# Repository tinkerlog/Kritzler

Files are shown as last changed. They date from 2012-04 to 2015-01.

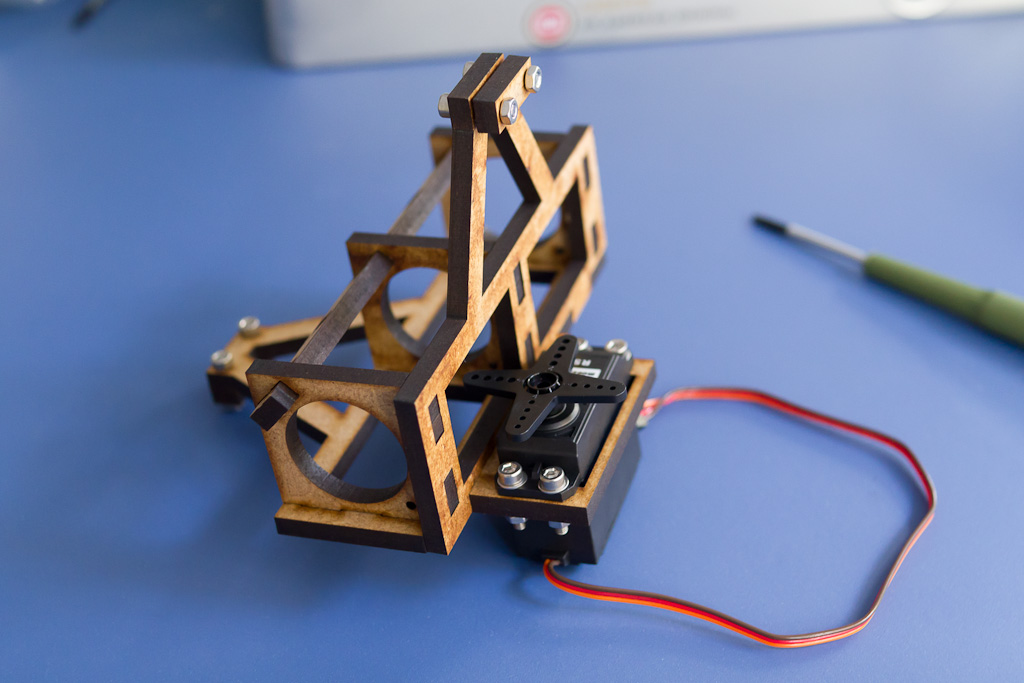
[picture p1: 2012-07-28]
doc/img/m_img-3472.jpg

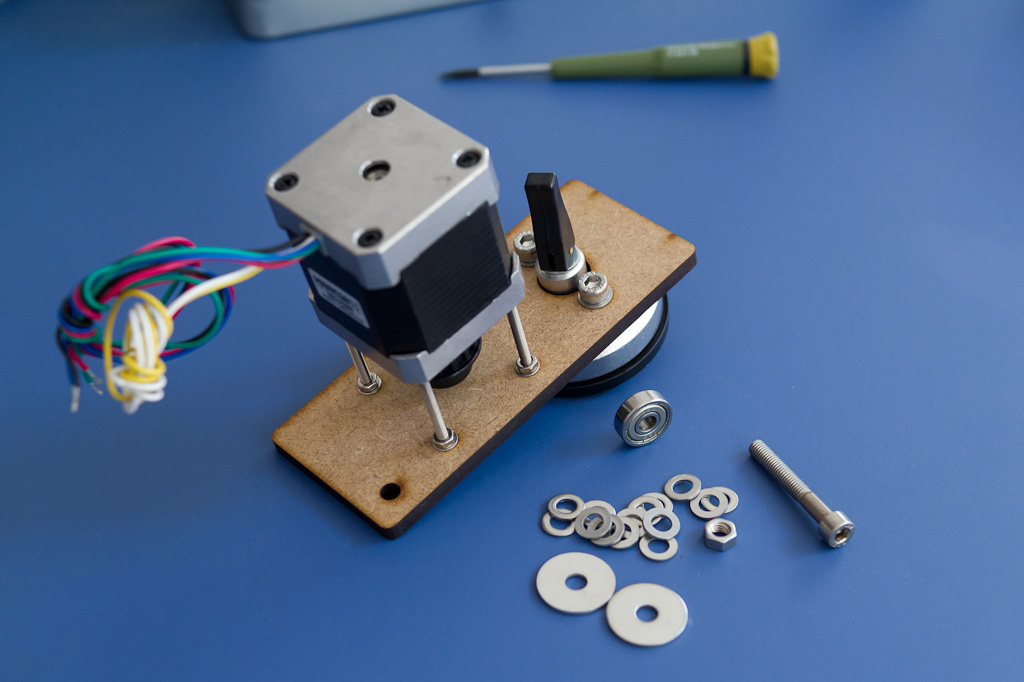
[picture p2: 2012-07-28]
doc/img/m_img-3442.jpg

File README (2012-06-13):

==============
 Der Kritzler
==============

 Der Kritzler is a software and hardware platform for developing wall plotters. 
 It consists of a set of Processing sketches (see src/ folder), Arduino firmware 
 (firmware/ folder) and some electronics (some files in the design/ folder). 

 More can be found here:
 http://tinkerlog.com/2011/09/02/der-kritzler/
 
 If you want me to pull your changes, please consider:
 * Use spaces, no tabs.
 * Indention: 2 spaces.

 src/ 
      Contains Processing/Java sources, ready to use in Eclipse.
      Take a look at http://processing.org/learning/eclipse/
      to see how to set things up.
      
 firmware/
      Contains Arduino firmware for the Kritzler.

 jpg_to_svg_bw.sh
      Script to convert a bitmap into an SVG.
      Needs imagemagick and potrace.
    
 jpg_to_svg.sh
      Starts the processing sketch to make a jittered SVG
      out of a bitmap (JPG).
      
 fill_svg.sh 
      Starts the processing sketch to fill SVG outlines with
      with diagonal lines.
      
 plotter.sh
      Starts the processing sketch that sends SVGs to the Kritzler.

===========
 Changelog
===========
 + Added controlP5 menus and buttons to the Plotter UI.
 + Added real-time pen location tracking - Jason Webb (5/25/2012)
 + Added Javadoc comments and consistent formatting added by - Jason Webb (5/25/2012)
 + Added ability to navigate through all SVG files in BUFFER_ACC folder using [ (back) and ] (forward) - Jason Webb (5/31/2012)
 + Added toggle-able grid to canvas, for accurate positioning (toggle with 'g') - Jason Webb (6/1/2012)
 + Added toggle-able bounding box for SVG shape, with centroid markings, for accurate positioning (toggle with 'b') - Jason Webb (6/1/2012)
 + Background color (canvas border) now changes to reflect state of pen plotter (same color as pen location marker). - Jason Webb (6/3/2012)

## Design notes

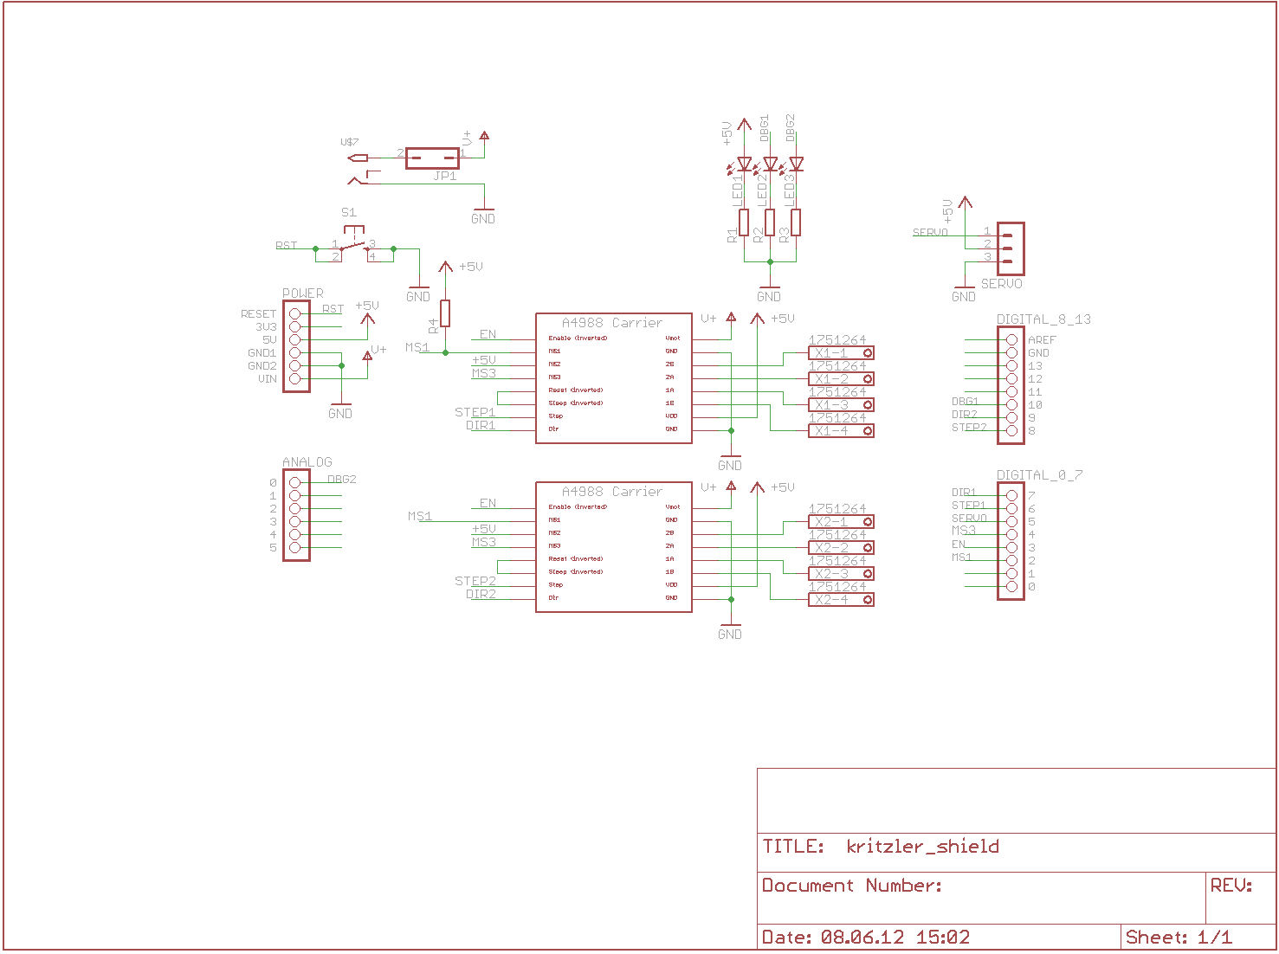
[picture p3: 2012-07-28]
design/eagle/kritzler_shield.png

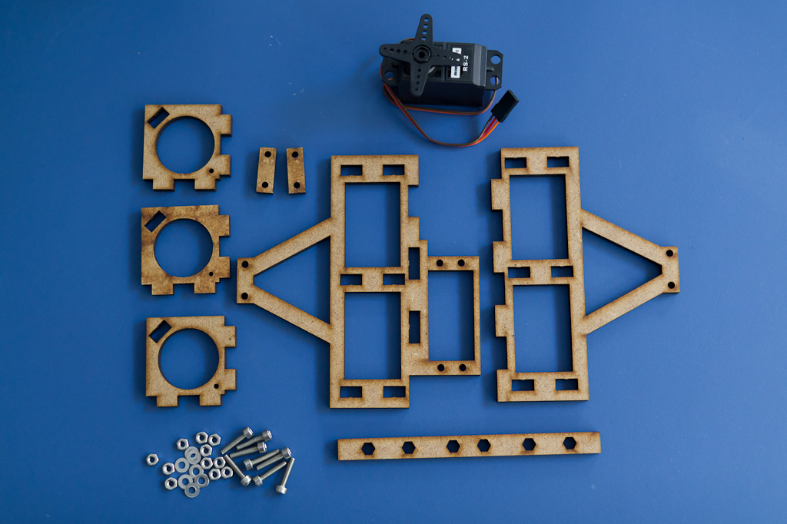
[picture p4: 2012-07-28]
doc/img/m_img-3462.jpg

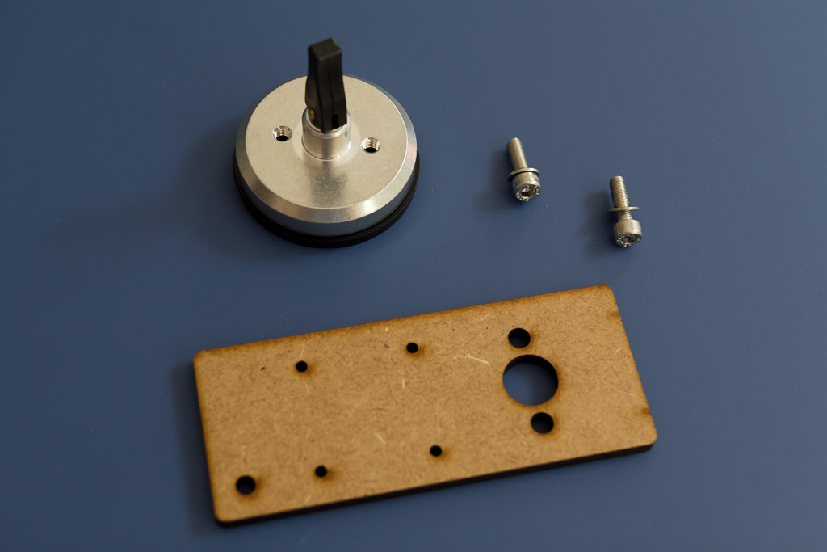
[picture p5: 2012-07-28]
doc/img/m_img-3431.jpg

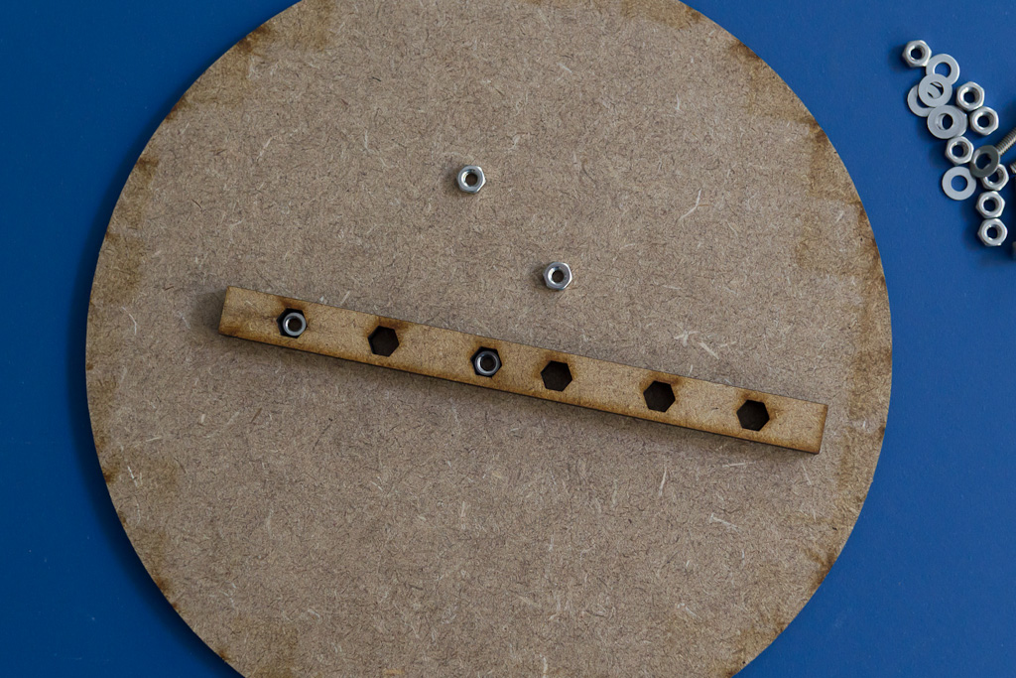
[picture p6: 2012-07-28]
doc/img/m_img-3469.jpg

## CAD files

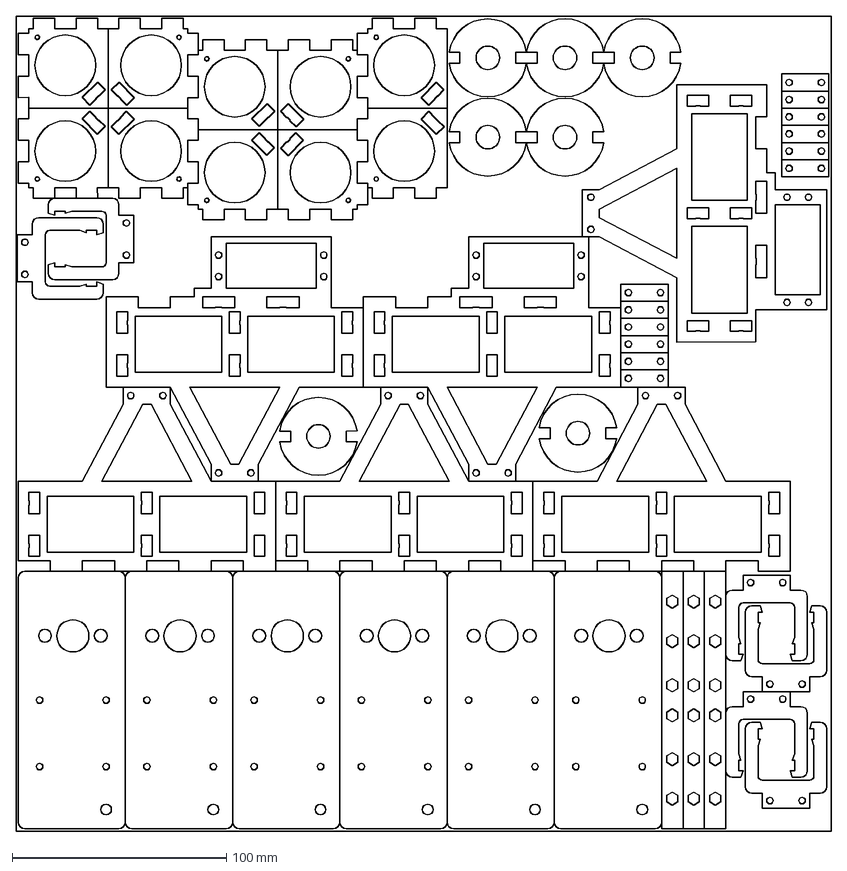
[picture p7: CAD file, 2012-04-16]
design/laser/kritzler.dxf
380.0 x 380.0 mm

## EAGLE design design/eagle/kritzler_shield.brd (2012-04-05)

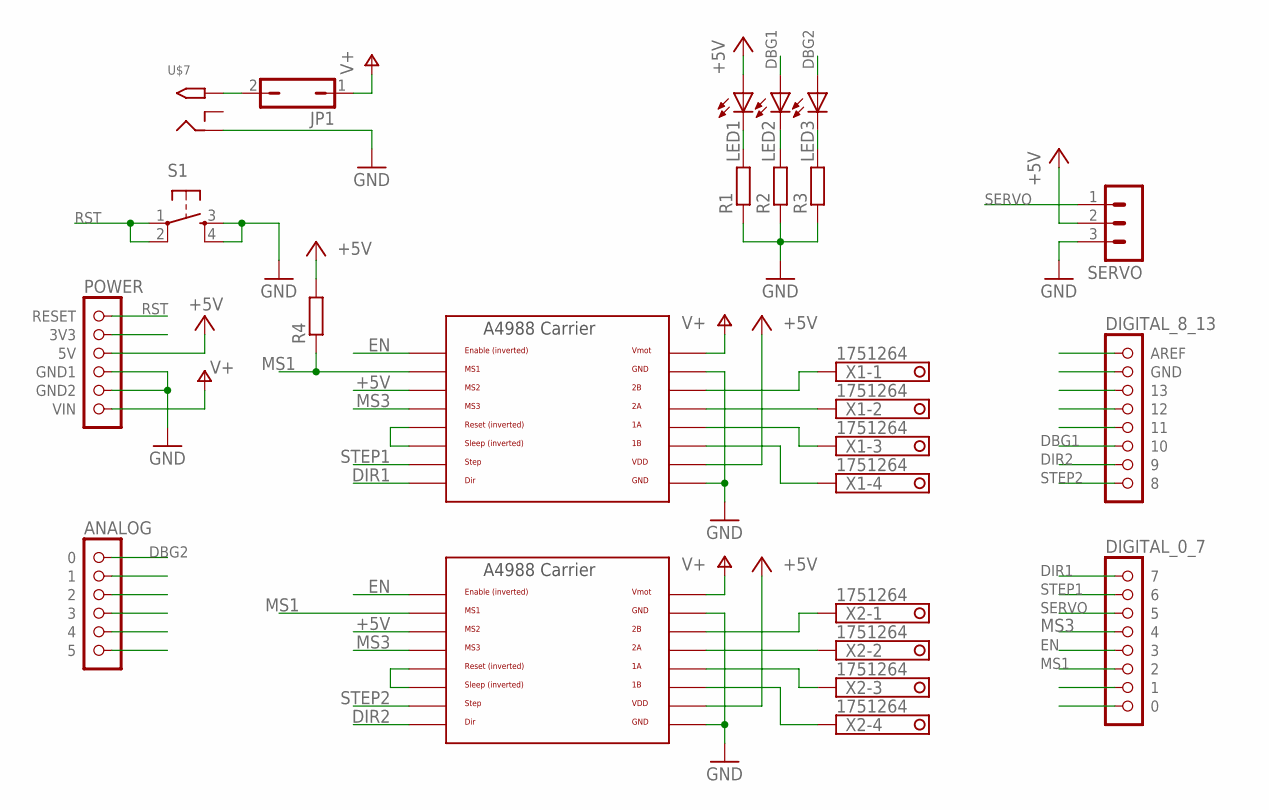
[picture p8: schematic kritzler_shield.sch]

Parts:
JP1: JP1Q; JP1
LED1, LED2, LED3: LED5MM
R1, R2, R3, R4: R-EU_0207/10; 0207/10
S1: TAC_SWITCHPTH; TACTILE-PTH
SERVO: MA03-1
U$1: POWER; 1X06
U$2: ANALOG; 1X06
U$3: DIGITAL_0_7; 1X08
U$4: DIGITAL_8_13; 1X08
U$5, U$6: A4988BREAKOUT
U$7: 2.1MMJACKTHM; PJ-102A
X1, X2: 1751264

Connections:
+5V: LED1.A, R4.2, SERVO.2, U$1.3 (5V), U$5.MS2, U$5.VDD, U$6.MS2, U$6.VDD
DBG1: LED2.A, U$4.6 (10)
DBG2: LED3.A, U$2.1 (0)
DIR1: U$3.1 (7), U$5.DIR
DIR2: U$4.7 (9), U$6.DIR
EN: U$3.5 (3), U$5.EN, U$6.EN
GND: R1.1, R2.1, R3.1, S1.3, S1.4, SERVO.3, U$1.4 (GND1), U$1.5 (GND2), U$5.GND, U$5.GND@0 (GND), U$6.GND, U$6.GND@0 (GND), U$7.RING
MS1: R4.1, U$3.6 (2), U$5.MS1, U$6.MS1
MS3: U$3.4, U$5.MS3, U$6.MS3
unnamed: JP1.2, U$7.TIP
unnamed: LED1.K (C), R1.2
unnamed: LED2.K (C), R2.2
unnamed: LED3.K (C), R3.2
unnamed: U$5.2A, X1.2
unnamed: U$5.1A, X1.3
unnamed: U$5.1B, X1.4
unnamed: U$5.2B, X1.1
unnamed: U$6.2A, X2.2
unnamed: U$6.2B, X2.1
unnamed: U$6.1A, X2.3
unnamed: U$6.1B, X2.4
unnamed: U$6.RST, U$6.SLP (SLEEP)
unnamed: U$5.RST, U$5.SLP (SLEEP)
RST: S1.1, S1.2, U$1.1 (RESET)
SERVO: SERVO.1, U$3.3 (5)
STEP1: U$3.2 (6), U$5.STEP
STEP2: U$4.8, U$6.STEP
T1: U$3.8 (0)
T2: U$3.7 (1)
V+: JP1.1, U$1.6 (VIN), U$5.VMOT, U$6.VMOT
X2: U$4.5 (11)
X3: U$4.4 (12)

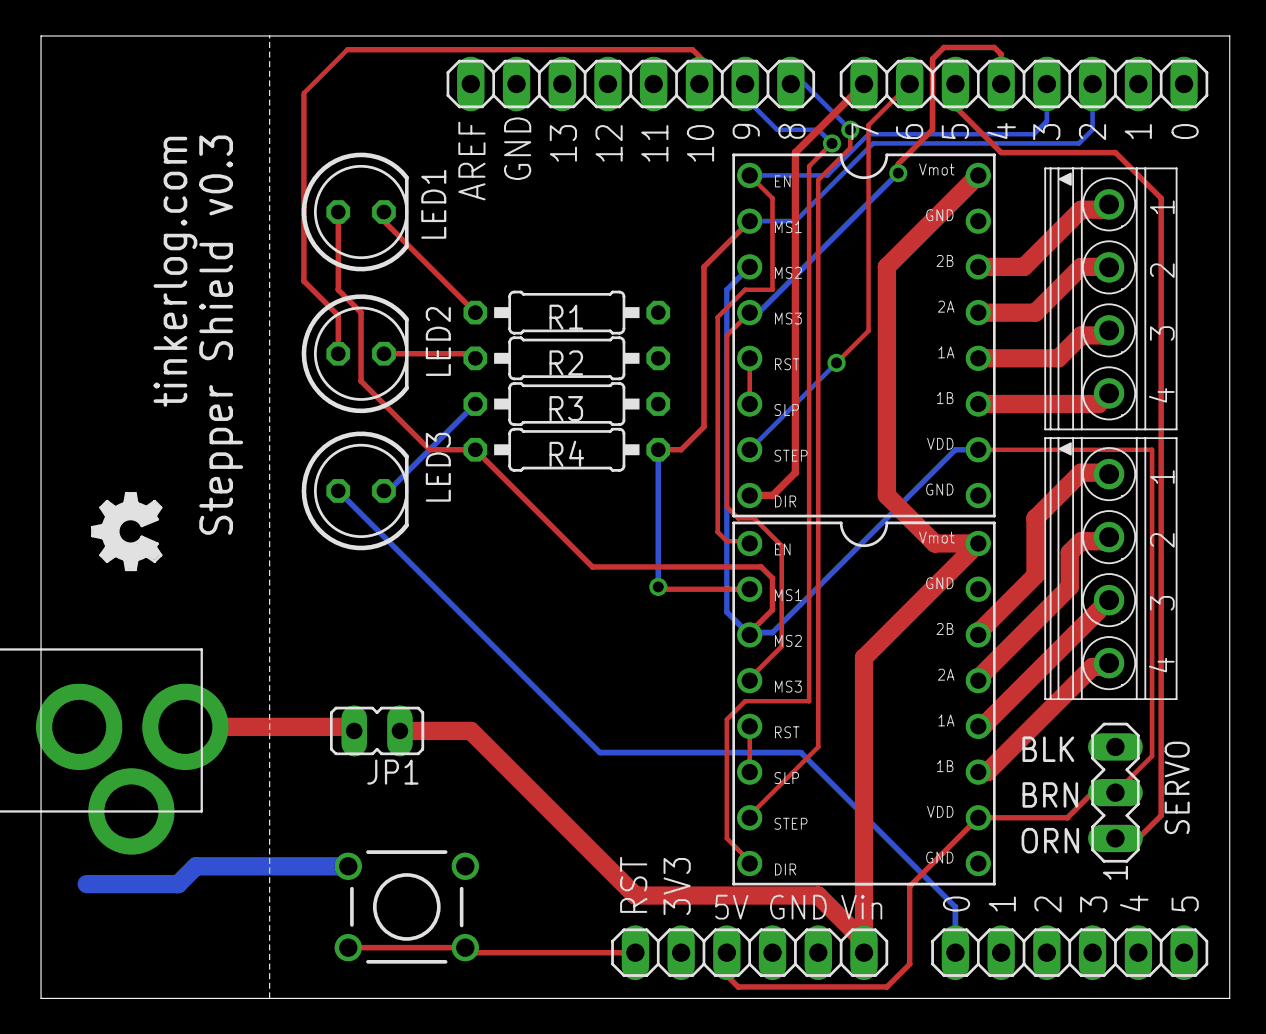
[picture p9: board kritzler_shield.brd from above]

Board: 2 copper layers, 66.0 x 53.5 mm, 20 parts (0 on the bottom side), 28 nets.

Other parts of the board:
U$8: OSHW_FILLX150_NOTEXT

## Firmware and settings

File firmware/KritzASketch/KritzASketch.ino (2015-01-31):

/*
 * Kritzelbot
 * Kritz-A-Sketch 
 *
 * motor
 * QSH4218-35-10-027
 *          Voltage = 5.3V
 *    Phase current = 1.0A
 * Phase resistance = 5 Ohm
 *        Full step = 1.8
 * red, blue, green, black
 *
 * 37.5 rot/m quarter step (1ms delay)
 *
 * LED_PIN2 --- 14
 * LED_PIN1 --- 10
 * DIR2     --- 9
 * STEP2    --- 8
 * DIR1     --- 7
 * STEP1    --- 6
 * SERVO    --- 5
 * MS3      --- 4
 * ENABLE   --- 3
 * MS1      --- 2 
 *
 *     TRI   SPA
 * A - BLK - RED
 * C - GRN - GRN
 * B - RED - YEL(BLK)
 * D - BLU - BLU
 *
 * Pololu - Mot(Tri) - Mot(Spa) - Mot(Pololu/1200)
 *     2B - BLK      - RED      - RED
 *     2A - BRN/GRN  - GRN      - BLU
 *     1A - BLU      - BLU      - GRN
 *     1B - RED      - BLK      - BLK
 *
 *
 *
 * MS1  | MS3  | 
 * -----+------+--------
 * LOW  | LOW  | quarter
 * HIGH | LOW  | eighth
 * HIGH | HIGH | sixteenth
 *
 */
 
#include <Servo.h>
#include <stdlib.h>
#include <Encoder.h>
#include <TimerThree.h>

// distance between both motors (axis) 150 cm
#define AXIS_DISTANCE_X 15000
#define AXIS_DISTANCE_Y 15000

// starting position
// a = b = 10607 --> 1060.7mm
// m2s = 0.7853982

#define START_X 7500
#define START_Y 7500
#define MIN_X 4000
#define MAX_X 11000
#define MIN_Y 4000
#define MAX_Y 12000

// pulley radius 10mm
//#define PULLEY_R 100
#define PULLEY_R 96
#define PI 3.14159
// circumference 2*PI*r = 62.8 mm 

// quarter step, 800 steps per rotation
#define STEPS_PER_ROT 800

// pen states
#define PEN_UP 0
#define PEN_DOWN 1
#define PEN_UP_POS 55
#define PEN_DOWN_POS 90
// delay to wait for the pen to go up or down
#define PEN_DELAY 1000

// default speed
#define PAUSE_DELAY 1

// possible commands
#define CMD_NONE 0
#define CMD_LINE_A 1
#define CMD_MOVE_A 2
#define CMD_LINE_R 3
#define CMD_MOVE_R 4
#define CMD_HELLO 5
#define CMD_END  6

// command chars
#define CMD_CHAR_LINE_A 'L'
#define CMD_CHAR_LINE_R 'l'
#define CMD_CHAR_MOVE_A 'M'
#define CMD_CHAR_MOVE_R 'm'
#define CMD_CHAR_OFF 'o'
#define CMD_CHAR_ON 'O'

// pin defines
#define MS1_PIN 2
#define ENABLE_PIN 3
#define MS3_PIN 4
#define SERVO_PIN 5
#define STEP_PIN_M1 6
#define DIR_PIN_M1 7
#define STEP_PIN_M2 8
#define DIR_PIN_M2 9
#define LED_PIN1 10
#define ENCX1 11
#define ENCX2 0
#define ENCY1 12
#define ENCY2 1
#define LIFT 13

#define LED_PIN2 14

#define MAX_BUFFER_SIZE 50

float m2s;
Servo servo;
Encoder encX(ENCX1, ENCX2);
Encoder encY(ENCY1, ENCY2);

long currentX = 0;
long currentY = 0;
long stepsM1 = 0;
long stepsM2 = 0;
long targetM1 = 0;
long targetM2 = 0;
byte penState = PEN_UP;

char line[MAX_BUFFER_SIZE];

typedef struct {
  char cmd;
  long x;
  long y;
  long targetM1;
  long targetM2;
} command;

#define MAX_COMMANDS 10
command cmdBuffer[MAX_COMMANDS];
byte readPtr = 0;
byte writePtr = 0;

long posX, posY;

void setup() {

  //while (!Serial) {
  //  ;
  //}
  if (Serial) {
    Serial.begin(57600);
    Serial.println("#start up");
  }

  // compute mm to steps
  m2s = (2 * PI * PULLEY_R) / STEPS_PER_ROT; 

  // compute starting pos
  currentX = START_X;
  currentY = START_Y;
  stepsM1 = computeA(START_X, START_Y) / m2s;
  stepsM2 = computeB(START_X, START_Y) / m2s;
  targetM1 = stepsM1;
  targetM2 = stepsM2;
  if (Serial) {
    Serial.print("#start steps: "); Serial.print(stepsM1); Serial.print(" "); Serial.println(stepsM2);
  }

  pinMode(MS1_PIN, OUTPUT);
  pinMode(MS3_PIN, OUTPUT);
  pinMode(ENABLE_PIN, OUTPUT);
  pinMode(DIR_PIN_M1, OUTPUT);
  pinMode(STEP_PIN_M1, OUTPUT);
  pinMode(DIR_PIN_M2, OUTPUT);
  pinMode(STEP_PIN_M2, OUTPUT);
  pinMode(LED_PIN1, OUTPUT);
  pinMode(LED_PIN2, OUTPUT);
  pinMode(LIFT, INPUT);

  // blinky hello  
  digitalWrite(LED_PIN1, HIGH);
  digitalWrite(LED_PIN2, LOW);
  delay(1000);
  digitalWrite(LED_PIN1, LOW);
  digitalWrite(LED_PIN2, HIGH);
  delay(1000);
  digitalWrite(LED_PIN1, HIGH);
  digitalWrite(LED_PIN2, LOW);  
  delay(1000);
  digitalWrite(LED_PIN1, LOW);

  digitalWrite(DIR_PIN_M2, LOW);
  digitalWrite(ENABLE_PIN, LOW);
  // set motors to quarter stepping
  digitalWrite(MS1_PIN, LOW);
  digitalWrite(MS3_PIN, LOW);
  
  // move pen up
  servo.attach(SERVO_PIN);
  penState = PEN_UP;
  servo.write(PEN_UP_POS);
  delay(500);
  
  // 16 MHz / 8 = 2 MHz (prescaler 8)
  // 2MHz / 256 = 7812.5 Hz
  // TCCR0A,TCCR0B,OCR0A,TIMSK0
  //TCCR1A = 0;           // normal operation                                                  
  //TCCR1B = (1<<CS01);   // prescaler 8                                                       
  //TIMSK1 = (1<<TOIE2);  // enable overflow interrupt    

  Timer3.initialize(125);
  Timer3.attachInterrupt(timer);  
  
  if (Serial) {
    while (Serial.available()) {
      Serial.read();
    }
  }
  
  servo.write(PEN_UP_POS);
  delay(1000);  
  servo.write(PEN_DOWN_POS);
  delay(1000);    
  servo.write(PEN_DOWN_POS);
  delay(1000);  

  if (Serial) {
    Serial.println("OK");
  }

}


// driver states 
#define D_STATE_IDLE 0 
#define D_STATE_PULSE 1
#define D_STATE_PULSE_DOWN 2
#define D_STATE_PAUSE 3
#define D_STATE_WAIT_SERVO 4

// motor directions
#define DIR_UP 1
#define DIR_DOWN 0

byte preScaler = 0;
byte newReadPtr;
word idleCount = 0;
word servoDelay = 0;
byte driverState = D_STATE_IDLE;
byte pause_count = 1;
int dsM1 = 0;
int dsM2 = 0;
int dM1 = 0;
int dM2 = 0;
int err = 0;
int e2 = 0;

/*
 * Timer overflow service routine
 */
//ISR(TIMER1_OVF_vect) {
void timer() {

  long tM1, tM2;
  byte cmd;

  preScaler++;
  if (preScaler < 4) {
    return;
  }
  preScaler = 0;

  switch (driverState) {
  case D_STATE_IDLE:
    if (writePtr != readPtr) {
      idleCount = 0;
      digitalWrite(ENABLE_PIN, LOW);
      digitalWrite(LED_PIN1, HIGH);
      newReadPtr = (readPtr + 1) % MAX_COMMANDS;
      // read the actual command 
      cmd = cmdBuffer[newReadPtr].cmd;
      if ((cmd != CMD_CHAR_ON) && (cmd != CMD_CHAR_OFF)) {
	tM1 = cmdBuffer[newReadPtr].targetM1;
	tM2 = cmdBuffer[newReadPtr].targetM2;
	// compute deltas
	dM1 = abs(tM1 - stepsM1);
	dM2 = abs(tM2 - stepsM2);
	err = dM1 - dM2;
	// set directions
	dsM1 = (tM1 > stepsM1) ? +1 : -1;
	dsM2 = (tM2 > stepsM2) ? +1 : -1;
	digitalWrite(DIR_PIN_M1, (tM1 > stepsM1) ? DIR_UP : DIR_DOWN);
	digitalWrite(DIR_PIN_M2, (tM2 > stepsM2) ? DIR_DOWN : DIR_UP);
	targetM1 = tM1;
	targetM2 = tM2;
	// go to pulsing/stepping state ...
	driverState = D_STATE_PULSE;      
      }
      // ... but move the pen up or down before, if needed
      switch (cmd) {
      case CMD_CHAR_ON:
	digitalWrite(LED_PIN1, HIGH);
        digitalWrite(ENABLE_PIN, LOW);
	readPtr = newReadPtr;
	break;
      case CMD_CHAR_OFF:
	digitalWrite(LED_PIN1, LOW);
        digitalWrite(ENABLE_PIN, HIGH);
	readPtr = newReadPtr;
	break;
      case CMD_CHAR_MOVE_A:
      case CMD_CHAR_MOVE_R:
	if (penState == PEN_DOWN) {
	  penState = PEN_UP;
	  servo.write(PEN_UP_POS);
	  driverState = D_STATE_WAIT_SERVO;
	}
	break;
      case CMD_CHAR_LINE_A:
      case CMD_CHAR_LINE_R:
	if (penState == PEN_UP) {
	  penState = PEN_DOWN;
	  servo.write(PEN_DOWN_POS);
	  driverState = D_STATE_WAIT_SERVO;
	}
	break;
      }
      /*
      Serial.print("state: ");
      Serial.println(driverState, DEC);
      Serial.print("target: ");
      Serial.print(targetM1);
      Serial.print(", ");
      Serial.print(targetM2);
      Serial.print(", delta: ");
      Serial.print(dsM1);
      Serial.print(", ");
      Serial.println(dsM2);
      */
    }
    else {
      /*
      idleCount++;
      if (idleCount == 10000) {
	// disable the motors if not in use
        digitalWrite(LED_PIN1, LOW);
        digitalWrite(ENABLE_PIN, HIGH);
      }
      */
    }
    break;
  case D_STATE_WAIT_SERVO:
    if (servoDelay++ >= PEN_DELAY) {
      driverState = D_STATE_PULSE;
      servoDelay = 0;
    }
    break;
  case D_STATE_PULSE:
    e2 = err * 2;
    if (e2 > -dM2) {
      err = err - dM2;
      digitalWrite(STEP_PIN_M1, HIGH);
      stepsM1 += dsM1;
    }
    if (e2 < dM1) {
      err = err + dM1;
      digitalWrite(STEP_PIN_M2, HIGH);
      stepsM2 += dsM2;
    }
    /*
    Serial.print("steps: ");
    Serial.print(stepsM1);
    Serial.print(", ");
    Serial.print(stepsM2);
    Serial.print(", ");
    Serial.print(targetM1);
    Serial.print(", ");
    Serial.println(targetM2);
    */
    pause_count = 0;
    driverState = D_STATE_PULSE_DOWN;
    break;
  case D_STATE_PULSE_DOWN:
    digitalWrite(STEP_PIN_M1, LOW);
    digitalWrite(STEP_PIN_M2, LOW);
    if ((stepsM1 == targetM1) && (stepsM2 == targetM2)) {
      driverState = D_STATE_IDLE;
      // signal that we have consumed the command by advancing the read pointer
      readPtr = newReadPtr;
    }
    else if (pause_count < PAUSE_DELAY) {
      driverState = D_STATE_PAUSE;
    }
    else {
      driverState = D_STATE_PULSE;
    }
    break;
  case D_STATE_PAUSE:
    if (++pause_count >= PAUSE_DELAY) {
      driverState = D_STATE_PULSE;
    }
    break;
  }
}

int computeA(long x, long y) {
  return sqrt(x * x + y * y);
}
  
int computeB(long x, long y) {
  long distanceX = AXIS_DISTANCE_X - x;
  return sqrt((distanceX * distanceX) + y * y);
}

char *readToken(char *str, char *buf, char delimiter) {
  uint8_t c = 0;
  while (true) {
    c = *str++;
    if ((c == delimiter) || (c == '\0')) {
      break;
    }
    else if (c != ' ') {
      *buf++ = c;
    }
  }
  *buf = '\0';
  return str;
}

byte parseLine(char *line) {

  byte newWritePtr;
  char tcmd;
  long tx = 0, ty = 0;
  long a, b;
  char buf[10];

  digitalWrite(LED_PIN2, HIGH);

  // wait until there is space for this command
  do {
    newWritePtr = (writePtr+1) % MAX_COMMANDS;
    if (newWritePtr == readPtr) {
      delay(1000);
      Serial.println("#waiting ...");
    }
  } while (newWritePtr == readPtr);

  switch (line[0]) {
  case 'm':
  case 'l':
    tcmd = line[0];
    line += 2; // skip command and space
    line = readToken(line, buf, ' ');
    tx = atol(buf) + currentX;
    line = readToken(line, buf, ' ');
    ty = atol(buf) + currentY;
    break;
  case 'M':
  case 'L':
    tcmd = line[0];
    line += 2; // skip command and space
    line = readToken(line, buf, ' ');
    tx = atol(buf);
    line = readToken(line, buf, ' ');
    ty = atol(buf);
    break;
  case 'O':
  case 'o':
    tcmd = line[0];
    tx = currentX;
    ty = currentY;
    break;
  default:
    Serial.print("#unknown command: ");
    Serial.println(line[0]);
    return 1;
  }

  if (tx < MIN_X) tx = MIN_X;
  if (tx > MAX_X) tx = MAX_X;
  if (ty < MIN_Y) ty = MIN_Y;
  if (ty > MAX_Y) ty = MAX_Y;

  Serial.print("#cmd: ");
  Serial.print(tcmd);
  Serial.print(", x:" );
  Serial.print(tx);
  Serial.print(", y:");
  Serial.println(ty);

  // compute a and b from x and y
  a = computeA(tx, ty);
  b = computeB(tx, ty);

  currentX = tx;
  currentY = ty;
  cmdBuffer[newWritePtr].x = tx;
  cmdBuffer[newWritePtr].y = ty;
  cmdBuffer[newWritePtr].cmd = tcmd;
  cmdBuffer[newWritePtr].targetM1 = a / m2s;  // convert to steps for motor 1
  cmdBuffer[newWritePtr].targetM2 = b / m2s;  // convert to steps for motor 2

  // advance the write ptr
  writePtr = newWritePtr;

  digitalWrite(LED_PIN2, LOW);
  Serial.println("OK");
  return 0;
}

byte readLine(char *line, byte size) {
  byte length = 0;
  char c;
  while (length < size) {
    if (Serial.available()) {
      c = Serial.read();
      length++;
      if ((c == '\r') || (c == '\n')) {
	*line = '\0';
        break;
      }
      *line++ = c;
    }
  }
  return length;
}


long i = 0;

int delta = 10;
byte switchPos = 0;

void loop() {

  /*
  if (i++ % 1000 == 0) {
    Serial.print("steps: ");
    Serial.print(stepsM1);
    Serial.print(", ");
    Serial.println(stepsM2);
    
    Serial.print("lift: ");
    Serial.println(digitalRead(LIFT));
  }
  */
    
  byte newSwitch = digitalRead(LIFT);
  if (newSwitch != switchPos) {
    if (newSwitch) {
      servo.write(PEN_UP_POS);
    }   
    else  {
      servo.write(PEN_DOWN_POS);
    }
    switchPos = newSwitch;    
  }  
    
    
  byte newWritePtr;
  char tcmd;
  long tx = 0, ty = 0;
  long a, b;

  long newPosX = encX.read();
  long newPosY = encY.read();
  // posX += newPosX;
  // posY += newPosY;
  if (newPosX != posX || newPosY != posY) {
    /*
    Serial.print("x: "); Serial.print(newPosX);
    Serial.print(", y: "); Serial.println(newPosY);
    
    // wait until there is space for this command
    Serial.print("writePtr: ");
    Serial.print(writePtr);    
    Serial.print(", readPtr: ");
    Serial.println(readPtr);
    */
    
    newWritePtr = (writePtr+1) % MAX_COMMANDS;
    if (newWritePtr == readPtr) {
      // Serial.println("#waiting ...");
      delay(10);
      return;
    }
    
    tx = currentX;
    ty = currentY;
    if (newPosX > posX) {
      tx = currentX + delta;
    }
    else if (newPosX < posX) {
      tx = currentX - delta;
    }
    if (newPosY > posY) {
      ty = currentY + delta;
    }
    else if (newPosY < posY) {
      ty = currentY - delta;
    }
    
    /*
    Serial.print("x/y: ");
    Serial.print(tx);
    Serial.print(", ");
    Serial.println(ty);
    */
  
  a = computeA(tx, ty);
  b = computeB(tx, ty);
  
    /*
    Serial.print("a/b: ");
    Serial.print(a);
    Serial.print(", ");
    Serial.println(b);
    */

  
  currentX = tx;
  currentY = ty;
  cmdBuffer[newWritePtr].x = tx;
  cmdBuffer[newWritePtr].y = ty;
  cmdBuffer[newWritePtr].cmd = tcmd;
  cmdBuffer[newWritePtr].targetM1 = a / m2s;  // convert to steps for motor 1
  cmdBuffer[newWritePtr].targetM2 = b / m2s;  // convert to steps for motor 2
  /*
  Serial.print("target: ");
  Serial.print(newWritePtr);
  Serial.print(", ");
  Serial.print(cmdBuffer[newWritePtr].targetM1);
  Serial.print(", ");
  Serial.println(cmdBuffer[newWritePtr].targetM2);
  */

  // advance the write ptr
  writePtr = newWritePtr;   

    posX = newPosX;
    posY = newPosY;
  

  }

}

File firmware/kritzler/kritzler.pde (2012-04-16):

/*
 * Kritzelbot
 *
 * motor
 * QSH4218-35-10-027
 *          Voltage = 5.3V
 *    Phase current = 1.0A
 * Phase resistance = 5 Ohm
 *        Full step = 1.8
 * red, blue, green, black
 *
 * 37.5 rot/m quarter step (1ms delay)
 *
 */
 
#include <Servo.h>
#include <stdlib.h>

#define PB1 1
#define PB2 2
#define PB3 3
#define PB4 4
#define PB5 5

// distance between both motors (axis) 150 cm
#define AXIS_DISTANCE_X 15000
#define AXIS_DISTANCE_Y 15000

// starting position
// a = b = 10607 --> 1060.7mm
// m2s = 0.7853982
//#define START_STEPS_M1 13505
//#define START_STEPS_M2 13505

#define START_X 7500
#define START_Y 7500

// pulley radius 10mm
#define PULLEY_R 100
#define PI 3.14159
// circumference 2*PI*r = 62.8 mm 
#define CIRCUMFERENCE 628

// quarter step, 800 steps per rotation
#define STEPS_PER_ROT 800

// motor directions
#define DIR_UP 1
#define DIR_DOWN 0

// pen states
#define PEN_UP 0
#define PEN_DOWN 1
#define PEN_UP_POS 90
#define PEN_DOWN_POS 55
#define PEN_DELAY 500

// driver states 
#define D_STATE_IDLE 0 
#define D_STATE_PULSE 1
#define D_STATE_PULSE_DOWN 2
#define D_STATE_PAUSE 3

// main states
#define M_STATE_WAIT_READ 0
#define M_STATE_WAIT_IDLE 1
#define M_STATE_WAIT_NOT_IDLE 2

// default speed
#define PAUSE_DELAY 1

// possible commands
#define CMD_NONE 0
#define CMD_LINE_A 1
#define CMD_MOVE_A 2
#define CMD_LINE_R 3
#define CMD_MOVE_R 4
#define CMD_HELLO 5
#define CMD_END  6

#define SERVO_PIN 8


byte ledPin = 6; 
//byte ledPin = 13; 

byte stepPinM1 = 9;  // PB1
byte dirPinM1 = 10;  // PB2
byte stepPinM2 = 11; // PB3
byte dirPinM2 = 12;  // PB4

float m2s;
Servo servo;

int currentX = 0;
int currentY = 0;
byte currentCommand = CMD_NONE;

long targetX = 0;
long targetY = 0;
int dirM1 = 1;
int dirM2 = 1;
long stepsM1 = 0;
long stepsM2 = 0;
long targetM1 = 0;
long targetM2 = 0;
long dsM1 = 0;
long dsM2 = 0;
long dM1 = 0;
long dM2 = 0;
int err = 0;
int e2 = 0;
byte driverState = D_STATE_IDLE;
byte penState = PEN_UP;
byte mainState = M_STATE_WAIT_READ;

byte pause_count = 1;
byte newTarget = 0;

int led = 0;

byte cmdPtr;
byte cmpTop;

void setup() {

  // Serial.begin(38400);
  Serial.begin(57600);
  Serial.println("#start up");

  // compute mm to steps
  m2s = (2 * PI * PULLEY_R) / STEPS_PER_ROT; 

  // compute starting pos
  currentX = START_X;
  currentY = START_Y;
  targetX = currentX;
  targetY = currentY;
  stepsM1 = computeA(currentX, currentY) / m2s;
  stepsM2 = computeB(currentX, currentY) / m2s;
  targetM1 = stepsM1;
  targetM2 = stepsM2;
  Serial.print("#start XY: "); Serial.print(currentX); Serial.print(" "); Serial.println(currentY);
  Serial.print("#start steps: "); Serial.print(stepsM1); Serial.print(" "); Serial.println(stepsM2);

  pinMode(ledPin, OUTPUT);
  pinMode(dirPinM1, OUTPUT);
  pinMode(stepPinM1, OUTPUT);
  pinMode(dirPinM2, OUTPUT);
  pinMode(stepPinM2, OUTPUT);
  digitalWrite(dirPinM2, LOW);

  servo.attach(SERVO_PIN);
  penState = PEN_DOWN;
  penUp();

  // 8MHz / 8 = 1MHz (prescaler 8)
  // 1MHz / 256 = 3906 Hz
  TCCR2A = 0;           // normal operation                                                  
  TCCR2B = (1<<CS21);   // prescaler 8                                                       
  TIMSK2 = (1<<TOIE2);  // enable overflow interrupt                                         

  while (Serial.available()) {
    Serial.read();
  }
  Serial.println("OK");
}

void printState() {
  Serial.print("#state: ");
  Serial.print(driverState, DEC);
  Serial.print(", M1: ");
  Serial.print(stepsM1, DEC);
  Serial.print(", M2: ");
  Serial.println(stepsM2);
}


byte preScaler = 0;

ISR(TIMER2_OVF_vect) {

  preScaler++;
  if (preScaler < 2) {
    return;
  }
  preScaler = 0;

  switch (driverState) {
  case D_STATE_IDLE:
    if (newTarget) {
      newTarget = 0;
      digitalWrite(ledPin, HIGH);
      // compute deltas
      dM1 = abs(targetM1 - stepsM1);
      dM2 = abs(targetM2 - stepsM2);
      err = dM1 - dM2;
      // set directions
      dsM1 = (targetM1 > stepsM1) ? +1 : -1;
      dsM2 = (targetM2 > stepsM2) ? +1 : -1;
      digitalWrite(dirPinM1, (targetM1 > stepsM1) ? DIR_UP : DIR_DOWN);
      digitalWrite(dirPinM2, (targetM2 > stepsM2) ? DIR_DOWN : DIR_UP);
      driverState = D_STATE_PULSE;
    }
    break;
  case D_STATE_PULSE:
    e2 = err * 2;
    if (e2 > -dM2) {
      err = err - dM2;
      digitalWrite(stepPinM1, HIGH);
      stepsM1 += dsM1;
    }
    if (e2 < dM1) {
      err = err + dM1;
      digitalWrite(stepPinM2, HIGH);
      stepsM2 += dsM2;
    }
    pause_count = 0;
    driverState = D_STATE_PULSE_DOWN;
    break;
  case D_STATE_PULSE_DOWN:
    digitalWrite(stepPinM1, LOW);
    digitalWrite(stepPinM2, LOW);
    if ((stepsM1 == targetM1) && (stepsM2 == targetM2)) {
      driverState = D_STATE_IDLE;
      digitalWrite(ledPin, LOW);
    }
    else if (pause_count < PAUSE_DELAY) {
      driverState = D_STATE_PAUSE;
    }
    else {
      driverState = D_STATE_PULSE;
    }
    break;
  case D_STATE_PAUSE:
    if (++pause_count >= PAUSE_DELAY) {
      driverState = D_STATE_PULSE;
    }
    break;
  }
}


int computeA(long x, long y) {
  return sqrt(x * x + y * y);
}
  
int computeB(long x, long y) {
  long distanceX = AXIS_DISTANCE_X - x;
  return sqrt((distanceX * distanceX) + y * y);
}

void readToken(char *buf) {
  int c;
  while (true) {
    if (Serial.available()) {
      c = Serial.read();
      //DEBUG_PRINT(c);
      if ((c == ' ') || (c == 13) || (c == -1) || (c == ';')) {
        break;
      }
      *buf++ = c;
    }
  }
  *buf = '\0';
}

void skipWhiteSpace() {
  int c;
  while (true) {
    if (Serial.available()) {
      c = Serial.peek();
      if ((c != ' ') && (c != 13)) {
        break;
      }
      else {
	Serial.read();
      }
    }
  }
}

long readLong() {
  char buf[20]; 
  skipWhiteSpace();
  readToken(buf);
  // Serial.print("buf:");
  // Serial.println(buf);
  return atol(buf);
}

void penUp() {
  if (penState == PEN_DOWN) {
    penState = PEN_UP;
    servo.write(PEN_UP_POS);
    delay(PEN_DELAY);
  }
}

void penDown() {
  if (penState == PEN_UP) {
    penState = PEN_DOWN;
    servo.write(PEN_DOWN_POS);
    delay(PEN_DELAY);
  }
}


long a, b;
int cmd;
long newX, newY;
long arg1, arg2;
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

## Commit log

2011-09-02 missing design for the laser cutter
2012-03-09 new design files
    [kritzler.dxf, kritzler_shield.brd, kritzler_shield.sch]
2012-04-05 wiring fixed
    [kritzler_shield.brd, kritzler_shield.sch]
2012-04-16 removed unused parts
    [kritzler.dxf]
2012-05-26 Added real-time pen location tracking and loads of Javadoc comments
    [kritzler_shield.brd, kritzler_shield.sch]
2012-06-08 revert changes on schematics
    [kritzler_shield.brd, kritzler_shield.sch]
2012-06-13 added some controlP5 menus and buttons
